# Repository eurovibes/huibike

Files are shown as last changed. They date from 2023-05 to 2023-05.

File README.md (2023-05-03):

<!-- SPDX-FileCopyrightText: 2023 Benedikt Spranger <bene@eurovibes.org> -->
<!-- SPDX-License-Identifier: CERN-OHL-S-2.0 -->


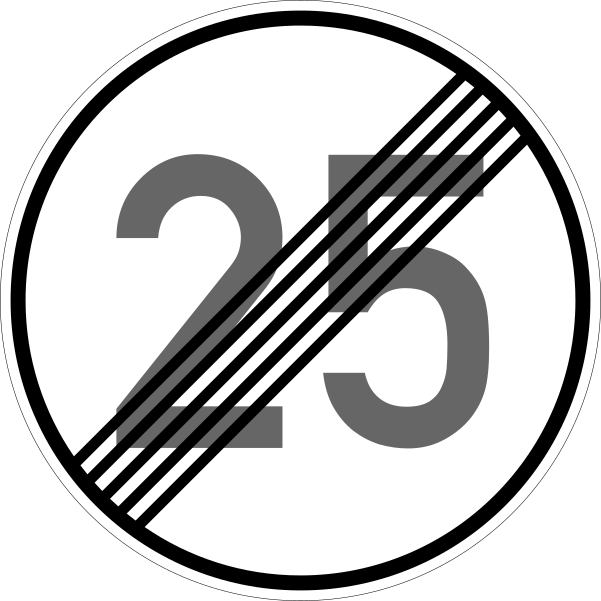
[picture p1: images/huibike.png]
huibike logo


# huibike - Bike magnet sensor adaption board

## License rules

huibike is provided under the terms of the CERN-OHL-S license version 2 as
provided in the LICENSES/CERN-OHL-S-2.0 file.

Instead of adding license boilerplates to the individual files, huibike uses
SPDX license identifiers, which are machine parseable and considered legaly
equivalent.

The SPDX license identifier in huibike shall be added at the first possible
line in a file which can contain a comment. This is normally the first line
except for scripts. Scripts require the #!PATH_TO_INTERPRETER tag in the
first line; place the SPDX identifier into the second line.

The SPDX license identifier is added in form of a comment.

## Copyright and License

Copyright Benedikt Spranger 2021.
This source describes Open Hardware and is licensed under the CERNOHL-S v2.
You may redistribute and modify this source and make products using it
under the terms of the CERN-OHL-S v2
(https://ohwr.org/cern ohl s v2.txt ).
This source is distributed WITHOUT ANY EXPRESS OR IMPLIED
WARRANTY, INCLUDING OF MERCHANTABILITY, SATISFACTORY
QUALITY AND FITNESS FOR A PARTICULAR PURPOSE. Please see
the CERN-OHL-S v2 for applicable conditions.
Source location: https://github.com/eurovibes/huibike
As per CERN-OHL-S v2 section 4, should You produce hardware based
on this source, You must where practicable maintain the Source Location
visible on the external case of the huibike or other products you make using
this source.

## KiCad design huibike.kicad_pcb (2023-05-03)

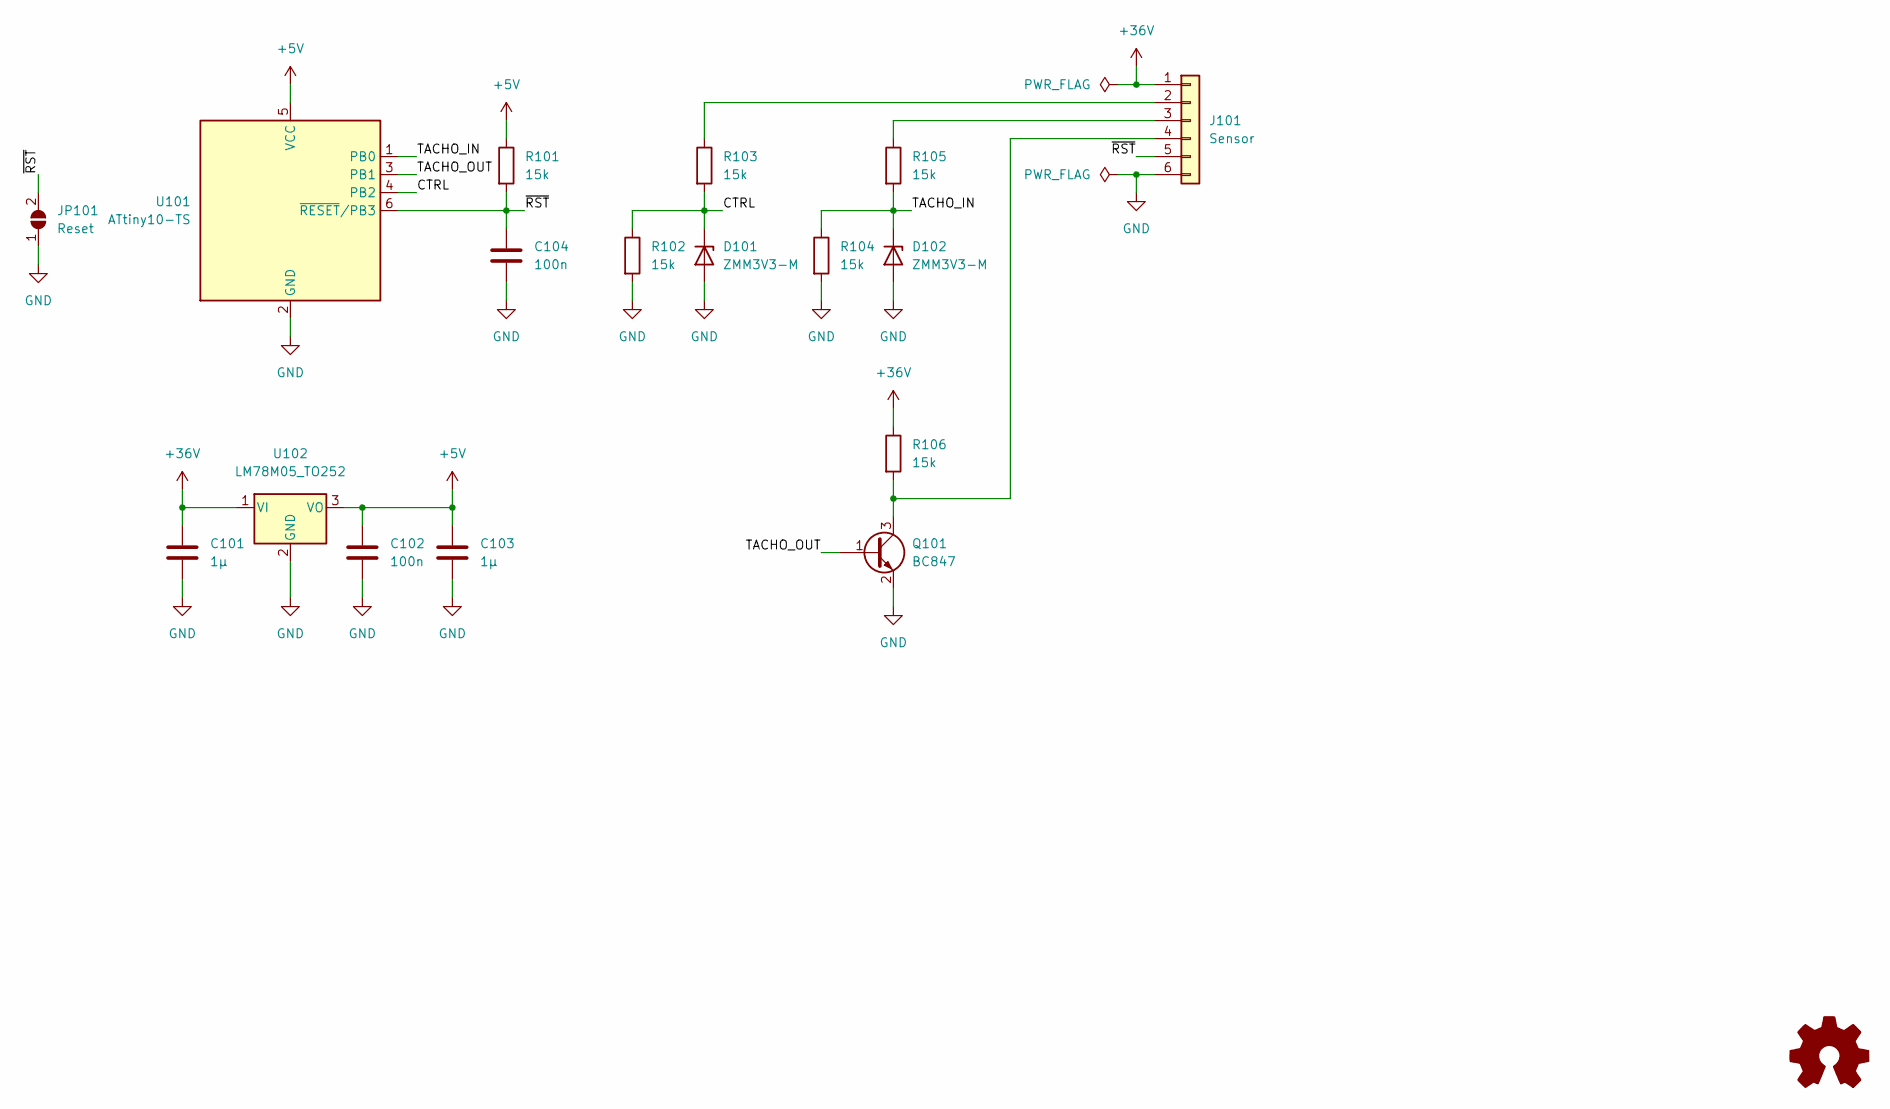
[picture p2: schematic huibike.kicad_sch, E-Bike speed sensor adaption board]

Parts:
C101, C103: 1µ; C_0805_2012Metric; LCSC# C28323
C102, C104: 100n; C_0402_1005Metric; LCSC# C1525
D101, D102: ZMM3V3-M; D_MiniMELF; LCSC# C8056
J101: Sensor; PinHeader_1x06_P2.54mm_Vertical
JP101: Reset; SolderJumper-2_P1.3mm_Open_Pad1.0x1.5mm
Q101: BC847; SOT-23; LCSC# C475630
R101, R102, R103, R104, R105, R106: 15k; R_0402_1005Metric; LCSC# C25756
U101: ATtiny10-TS; SOT-23-6; LCSC# C128438
U102: LM78M05_TO252; TO-252-2; LCSC# C58069

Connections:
+5V: C102.1, C103.1, R101.1, U101.5 (VCC), U102.3 (VO)
+36V: C101.1, J101.1, R106.1, U102.1 (VI)
/CTRL: D101.1 (K), R102.1, R103.2, U101.4 (PB2)
/TACHO_IN: D102.1 (K), R104.1, R105.2, U101.1 (PB0)
/TACHO_OUT: Q101.1 (B), U101.3 (PB1)
/~RST: C104.1, J101.5, JP101.2 (B), R101.2, U101.6 (~RESET/PB3)
GND: C101.2, C102.2, C103.2, C104.2, D101.2 (A), D102.2 (A), J101.6, JP101.1 (A), Q101.2 (E), R102.2, R104.2, U101.2 (GND), U102.2 (GND)
unnamed: J101.2, R103.1
unnamed: J101.3, R105.1
unnamed: J101.4, Q101.3 (C), R106.2

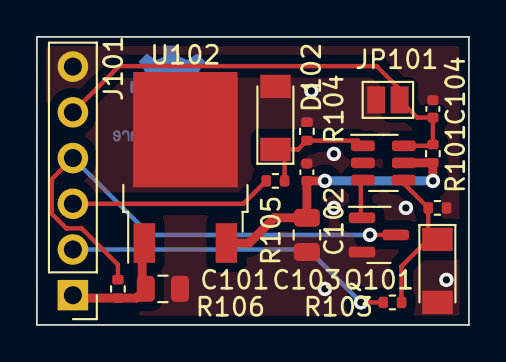
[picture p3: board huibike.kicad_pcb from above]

Board: 2 copper layers, 24.0 x 16.0 mm, 17 parts (0 on the bottom side), 10 nets.

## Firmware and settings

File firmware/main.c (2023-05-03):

#include <stdint.h>

#include <avr/io.h>

int main (void)
{
	uint8_t act, old, c = 0;

	DDRB  = 0x02;
	PORTB = 0x00;

	old = PORTB & 1;

	while (1)
	{
		act = PORTB & 1;
		if (act != old)
		{
			old = act;

			if (act)
			{
				c++;
				if ((PORTB & 4) && (c & 1))
					continue;

				PORTB |= 2;
			}
			else
				PORTB &= ~2;
		}
	}

	return 0;
}

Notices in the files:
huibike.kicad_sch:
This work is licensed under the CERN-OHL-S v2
